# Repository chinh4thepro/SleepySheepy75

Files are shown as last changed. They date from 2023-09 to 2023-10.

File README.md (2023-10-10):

# SleepySheepy75

Making a keyboard cause im bored

## Hardware

Uses a soldered on rp2040 as the MCU
- 85x diodes for each switch (one extra for knob switch)
- 1x rotary encoder (EC11(E))
- 84x hotswap sockets
- 1x W25Q128JVS as flash rom
- 1x USB-C as connector 
- 2x buttons for "boot" selection
- Other stuff for electrical stuff

## Software

It is to be ported to QMK and be supported with VIA/VIAL

## Design

TODO - Probably going to happen when I get the pcb, case is going to be available in variety of materials

## Progress

- [x] Design the schematic (Done on 2023-09-08)
- [x] Come up with a name + Design logo (Done on 2023-10-07 (Scrapped on PCB though))
- [x] Design the PCB (Done on 2023-09-17)
- [ ] Order the PCB and its parts
- [ ] Construct PCB
- [ ] Port QMK + VIA/VIAL
- [ ] Design case for a 3d printer
- [ ] Design case for acrylic stacking
- [ ] Design case for metal CNC

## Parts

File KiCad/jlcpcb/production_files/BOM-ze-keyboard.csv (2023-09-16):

Comment | Designator | Footprint | LCSC
1k | R6,R8 | R_0402_1005Metric | C11702
100nF | C13,C14,C15,C16,C2,C5,C6,C7 | C_0402_1005Metric | C1525
10uF | C3 | C_0603_1608Metric | C15525
22pF | C10,C12 | C_0402_1005Metric | C1555
USB_C_Receptacle_USB2.0 | J2 | USB_C_Receptacle_HRO_TYPE-C-31-M-12 | C165948
RP2040 | U2 | QFN-56-1EP_7x7mm_P0.4mm_EP3.2x3.2mm | C2040
500mA | F1 | Fuse_1206_3216Metric | C20798
10k | R11,R12 | R_0402_1005Metric | C25744
27 | R1,R2 | R_0402_1005Metric | C25771
5.1k | R3,R4,R5,R7,R9 | R_0402_1005Metric | C25905
Flash | SW1,SW2 | SW_SPST_TL3342 | C318884
RotaryEncoder_Switch | SW3 | RotaryEncoder_Alps_EC11E-Switch_Vertical_H20mm | C470710
MX_SW_HS | MX1,MX10,MX11,MX12,MX13,MX14,MX15,MX16,MX17,MX18,MX19,MX2,MX20,MX21,MX22,MX23,MX24,MX25,MX26,MX27,MX28,MX29,MX3,MX30,MX31,MX32,MX33,MX34,MX35,MX36,MX37,MX38,MX39,MX4,MX40,MX41,MX42,MX43,MX44,MX45,MX46,MX47,MX48,MX49,MX5,MX50,MX51,MX52,MX53,MX54,MX55,MX56,MX57,MX58,MX59,MX6,MX60,MX61,MX62,MX63,MX64,MX65,MX66,MX67,MX68,MX69,MX7,MX70,MX71,MX72,MX73,MX74,MX75,MX76,MX77,MX78,MX79,MX8,MX80,MX81,MX82,MX83,MX84,MX9 | SW_MX_HS_1u | C5156480
1uF | C1,C11,C4,C8,C9 | C_0402_1005Metric | C52923
XC6206PxxxMR | U1 | SOT-23-3 | C5446
Crystal_GND24_Small | Y1 | Crystal_SMD_3225-4Pin_3.2x2.5mm | C5765981
ESC | D1,D10,D11,D12,D13,D14,D15,D16,D17,D18,D19,D2,D20,D21,D22,D23,D24,D25,D26,D27,D28,D29,D3,D30,D31,D32,D33,D34,D35,D36,D37,D38,D39,D4,D40,D41,D42,D43,D44,D45,D46,D47,D48,D49,D5,D50,D51,D52,D53,D54,D55,D56,D57,D58,D59,D6,D60,D61,D62,D63,D64,D65,D66,D67,D68,D69,D7,D70,D71,D72,D73,D74,D75,D76,D77,D78,D79,D8,D80,D81,D82,D83,D84,D85,D9 | D_SOD-123 | C81598
SRV05-4 | U4 | SOT-23-6-routable | C85364
W25Q128JVS | U3 | SOIC-8_5.23x5.23mm_P1.27mm | C97521

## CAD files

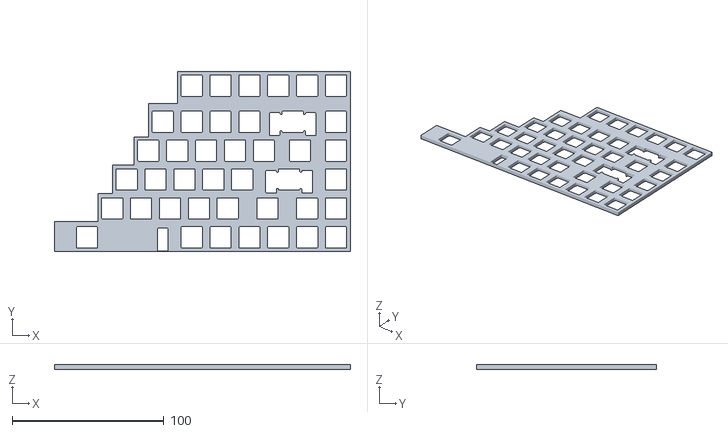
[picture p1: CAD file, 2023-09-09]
Plate/plate_half2.stl
195.3 x 119.1 x 3.00

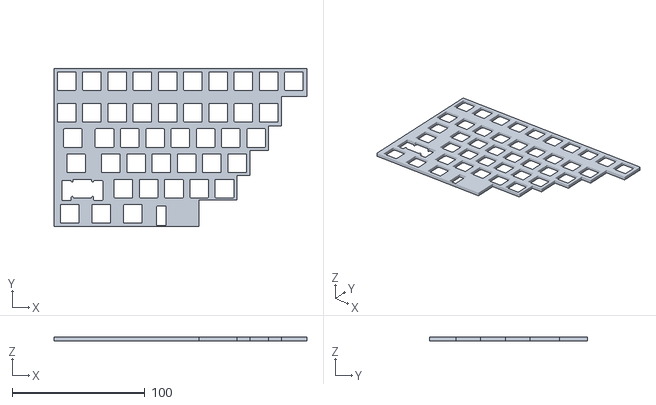
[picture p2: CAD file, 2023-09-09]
Plate/plate_half1.stl
190.8 x 119.1 x 3.00

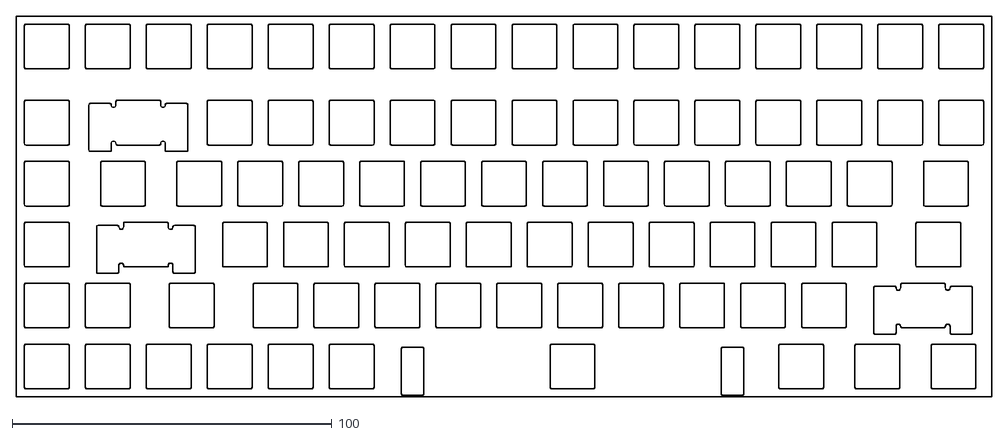
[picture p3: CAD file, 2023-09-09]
Plate/Plate-Combined.dxf
304.8 x 119.1

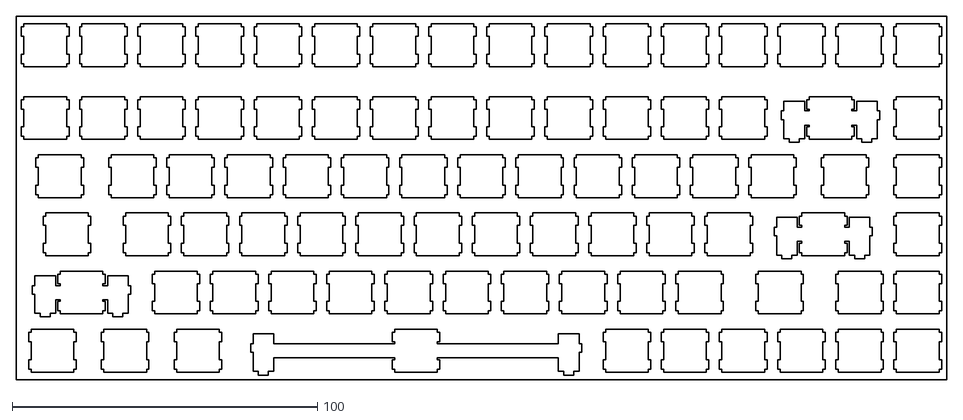
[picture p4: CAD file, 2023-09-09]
Plate/Keyboard_Plate_flat.dxf
304.8 x 119.1

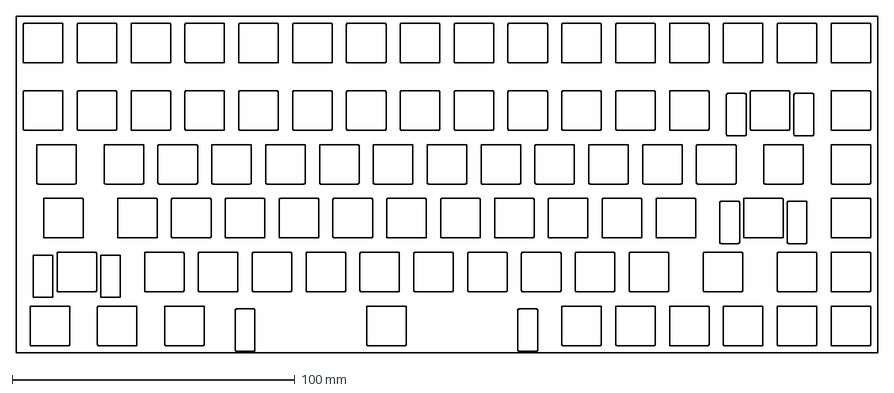
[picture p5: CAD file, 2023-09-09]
Plate/plate_ai03.dxf
304.8 x 119.1 mm

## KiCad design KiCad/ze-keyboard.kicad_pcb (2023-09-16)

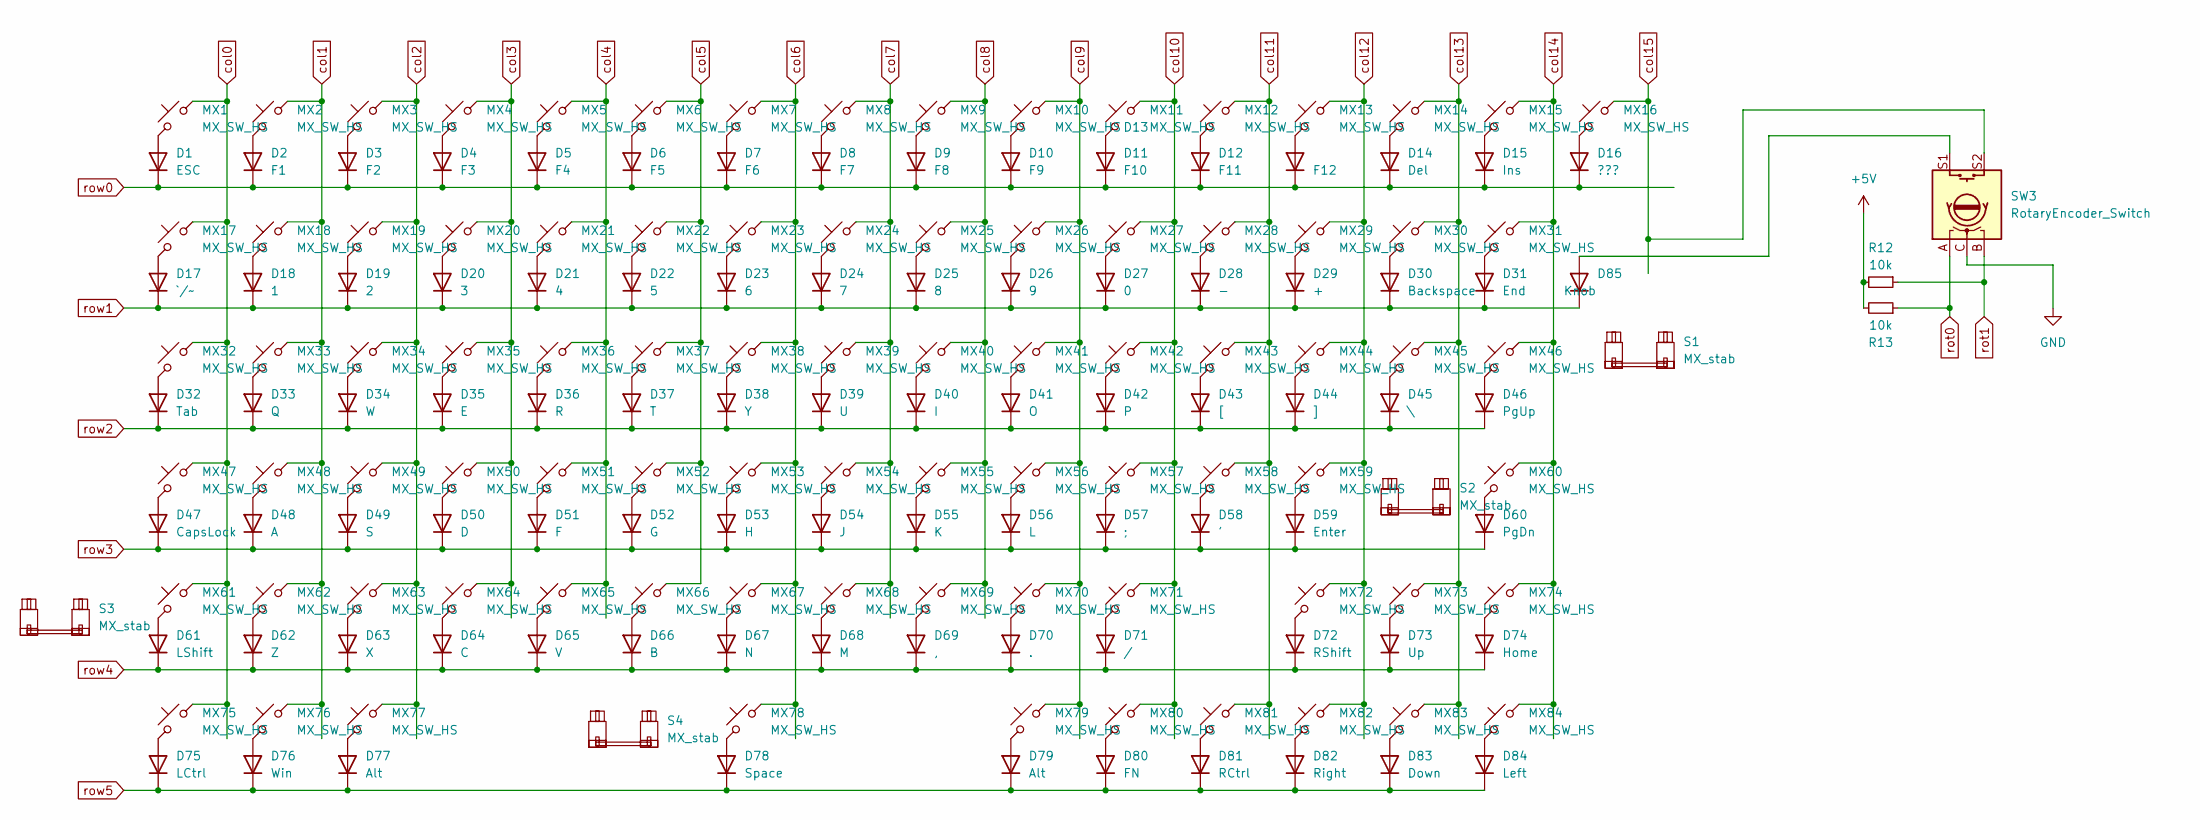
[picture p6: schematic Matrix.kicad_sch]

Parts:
D1: ESC; D_SOD-123
D2: F1; D_SOD-123
D3: F2; D_SOD-123
D4: F3; D_SOD-123
D5: F4; D_SOD-123
D6: F5; D_SOD-123
D7: F6; D_SOD-123
D8: F7; D_SOD-123
D9: F8; D_SOD-123
D10: F9; D_SOD-123
D11: F10; D_SOD-123
D12: F11; D_SOD-123
D13: F12; D_SOD-123
D14: Del; D_SOD-123
D15: Ins; D_SOD-123
D16: ???; D_SOD-123
D17: `/~; D_SOD-123
D18: 1; D_SOD-123
D19: 2; D_SOD-123
D20: 3; D_SOD-123
D21: 4; D_SOD-123
D22: 5; D_SOD-123
D23: 6; D_SOD-123
D24: 7; D_SOD-123
D25: 8; D_SOD-123
D26: 9; D_SOD-123
D27: 0; D_SOD-123
D28: -; D_SOD-123
D29: +; D_SOD-123
D30: Backspace; D_SOD-123
D31: End; D_SOD-123
D32: Tab; D_SOD-123
D33: Q; D_SOD-123
D34: W; D_SOD-123
D35: E; D_SOD-123
D36: R; D_SOD-123
D37: T; D_SOD-123
D38: Y; D_SOD-123
D39: U; D_SOD-123
D40: I; D_SOD-123
D41: O; D_SOD-123
D42: P; D_SOD-123
D43: [; D_SOD-123
D44: ]; D_SOD-123
D45: \; D_SOD-123
D46: PgUp; D_SOD-123
D47: CapsLock; D_SOD-123
D48: A; D_SOD-123
D49: S; D_SOD-123
D50: D; D_SOD-123
D51: F; D_SOD-123
D52: G; D_SOD-123
D53: H; D_SOD-123
D54: J; D_SOD-123
D55: K; D_SOD-123
D56: L; D_SOD-123
D57: ;; D_SOD-123
D58: '; D_SOD-123
D59: Enter; D_SOD-123
D60: PgDn; D_SOD-123
D61: LShift; D_SOD-123
D62: Z; D_SOD-123
D63: X; D_SOD-123
D64: C; D_SOD-123
D65: V; D_SOD-123
D66: B; D_SOD-123
D67: N; D_SOD-123
D68: M; D_SOD-123
D69: ,; D_SOD-123
D70: .; D_SOD-123
D71: /; D_SOD-123
D72: RShift; D_SOD-123
D73: Up; D_SOD-123
D74: Home; D_SOD-123
D75: LCtrl; D_SOD-123
D76: Win; D_SOD-123
D77, D79: Alt; D_SOD-123
D78: Space; D_SOD-123
D80: FN; D_SOD-123
D81: RCtrl; D_SOD-123
D82: Right; D_SOD-123
D83: Down; D_SOD-123
D84: Left; D_SOD-123
D85: Knob; D_SOD-123
MX1, MX2, MX3, MX4, MX5, MX6, MX7, MX8, MX9, MX10, MX11, MX12, MX13, MX14, MX15, MX16, MX17, MX18, MX19, MX20, MX21, MX22, MX23, MX24, MX25, MX26, MX27, MX28, MX29, MX30, MX31, MX32, MX33, MX34, MX35, MX36, MX37, MX38, MX39, MX40, MX41, MX42, MX43, MX44, MX45, MX46, MX47, MX48, MX49, MX50, MX51, MX52, MX53, MX54, MX55, MX56, MX57, MX58, MX59, MX60, MX61, MX62, MX63, MX64, MX65, MX66, MX67, MX68, MX69, MX70, MX71, MX72, MX73, MX74, MX75, MX76, MX77, MX78, MX79, MX80, MX81, MX82, MX83, MX84: MX_SW_HS; SW_MX_HS_1u
R12, R13: 10k; R_0402_1005Metric
S1, S2, S3: MX_stab; STAB_MX_P_2u
S4: MX_stab; STAB_MX_P_6.25u
SW3: RotaryEncoder_Switch; RotaryEncoder_Alps_EC11E-Switch_Vertical_H20mm

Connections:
+5V: R12.2; also elsewhere on the board
GND: SW3.C; also elsewhere on the board
unnamed: D1.2 (A), MX1.1
unnamed: D2.2 (A), MX2.1
unnamed: D3.2 (A), MX3.1
unnamed: D4.2 (A), MX4.1
unnamed: D5.2 (A), MX5.1
unnamed: D6.2 (A), MX6.1
unnamed: D7.2 (A), MX7.1
unnamed: D8.2 (A), MX8.1
unnamed: D9.2 (A), MX9.1
unnamed: D10.2 (A), MX10.1
unnamed: D11.2 (A), MX11.1
unnamed: D12.2 (A), MX12.1
unnamed: D13.2 (A), MX13.1
unnamed: D14.2 (A), MX14.1
unnamed: D15.2 (A), MX15.1
unnamed: D16.2 (A), MX16.1
unnamed: D17.2 (A), MX17.1
unnamed: D18.2 (A), MX18.1
unnamed: D19.2 (A), MX19.1
unnamed: D20.2 (A), MX20.1
unnamed: D21.2 (A), MX21.1
unnamed: D22.2 (A), MX22.1
unnamed: D23.2 (A), MX23.1
unnamed: D24.2 (A), MX24.1
unnamed: D25.2 (A), MX25.1
unnamed: D26.2 (A), MX26.1
unnamed: D27.2 (A), MX27.1
unnamed: D28.2 (A), MX28.1
unnamed: D29.2 (A), MX29.1
unnamed: D30.2 (A), MX30.1
unnamed: D31.2 (A), MX31.1
unnamed: D32.2 (A), MX32.1
unnamed: D33.2 (A), MX33.1
unnamed: D34.2 (A), MX34.1
unnamed: D35.2 (A), MX35.1
unnamed: D36.2 (A), MX36.1
unnamed: D37.2 (A), MX37.1
unnamed: D38.2 (A), MX38.1
unnamed: D39.2 (A), MX39.1
unnamed: D40.2 (A), MX40.1
unnamed: D41.2 (A), MX41.1
unnamed: D42.2 (A), MX42.1
unnamed: D43.2 (A), MX43.1
unnamed: D44.2 (A), MX44.1
unnamed: D45.2 (A), MX45.1
unnamed: D46.2 (A), MX46.1
unnamed: D47.2 (A), MX47.1
unnamed: D48.2 (A), MX48.1
unnamed: D49.2 (A), MX49.1
unnamed: D50.2 (A), MX50.1
unnamed: D51.2 (A), MX51.1
unnamed: D52.2 (A), MX52.1
unnamed: D53.2 (A), MX53.1
unnamed: D54.2 (A), MX54.1
unnamed: D55.2 (A), MX55.1
unnamed: D56.2 (A), MX56.1
unnamed: D57.2 (A), MX57.1
unnamed: D58.2 (A), MX58.1
unnamed: D59.2 (A), MX59.1
unnamed: D60.2 (A), MX60.1
unnamed: D61.2 (A), MX61.1
unnamed: D62.2 (A), MX62.1
unnamed: D63.2 (A), MX63.1
unnamed: D64.2 (A), MX64.1
unnamed: D65.2 (A), MX65.1
unnamed: D66.2 (A), MX66.1
unnamed: D67.2 (A), MX67.1
unnamed: D68.2 (A), MX68.1
unnamed: D69.2 (A), MX69.1
unnamed: D70.2 (A), MX70.1
unnamed: D71.2 (A), MX71.1
unnamed: D72.2 (A), MX72.1
unnamed: D73.2 (A), MX73.1
unnamed: D74.2 (A), MX74.1
unnamed: D75.2 (A), MX75.1
unnamed: D76.2 (A), MX76.1
unnamed: D77.2 (A), MX77.1
unnamed: D78.2 (A), MX78.1
unnamed: D79.2 (A), MX79.1
unnamed: D80.2 (A), MX80.1
unnamed: D81.2 (A), MX81.1
unnamed: D82.2 (A), MX82.1
unnamed: D83.2 (A), MX83.1
unnamed: D84.2 (A), MX84.1
unnamed: D85.2 (A), SW3.S1
col0: MX1.2, MX17.2, MX32.2, MX47.2, MX61.2, MX75.2; also elsewhere on the board
col1: MX2.2, MX18.2, MX33.2, MX48.2, MX62.2, MX76.2; also elsewhere on the board
col2: MX3.2, MX19.2, MX34.2, MX49.2, MX63.2, MX77.2; also elsewhere on the board
col3: MX4.2, MX20.2, MX35.2, MX50.2, MX64.2; also elsewhere on the board
col4: MX5.2, MX21.2, MX36.2, MX51.2, MX65.2; also elsewhere on the board
col5: MX6.2, MX22.2, MX37.2, MX52.2, MX66.2; also elsewhere on the board
col6: MX7.2, MX23.2, MX38.2, MX53.2, MX67.2, MX78.2; also elsewhere on the board
col7: MX8.2, MX24.2, MX39.2, MX54.2, MX68.2; also elsewhere on the board
col8: MX9.2, MX25.2, MX40.2, MX55.2, MX69.2; also elsewhere on the board
col9: MX10.2, MX26.2, MX41.2, MX56.2, MX70.2, MX79.2; also elsewhere on the board
col10: MX11.2, MX27.2, MX42.2, MX57.2, MX71.2, MX80.2; also elsewhere on the board
col11: MX12.2, MX28.2, MX43.2, MX58.2, MX81.2; also elsewhere on the board
col12: MX13.2, MX29.2, MX44.2, MX59.2, MX72.2, MX82.2; also elsewhere on the board
col13: MX14.2, MX30.2, MX45.2, MX73.2, MX83.2; also elsewhere on the board
col14: MX15.2, MX31.2, MX46.2, MX60.2, MX74.2, MX84.2; also elsewhere on the board
col15: MX16.2, SW3.S2; also elsewhere on the board
row0: D1.1 (K), D2.1 (K), D3.1 (K), D4.1 (K), D5.1 (K), D6.1 (K), D7.1 (K), D8.1 (K), D9.1 (K), D10.1 (K), D11.1 (K), D12.1 (K), D13.1 (K), D14.1 (K), D15.1 (K), D16.1 (K); also elsewhere on the board
row1: D17.1 (K), D18.1 (K), D19.1 (K), D20.1 (K), D21.1 (K), D22.1 (K), D23.1 (K), D24.1 (K), D25.1 (K), D26.1 (K), D27.1 (K), D28.1 (K), D29.1 (K), D30.1 (K), D31.1 (K), D85.1 (K); also elsewhere on the board
row2: D32.1 (K), D33.1 (K), D34.1 (K), D35.1 (K), D36.1 (K), D37.1 (K), D38.1 (K), D39.1 (K), D40.1 (K), D41.1 (K), D42.1 (K), D43.1 (K), D44.1 (K), D45.1 (K), D46.1 (K); also elsewhere on the board
row3: D47.1 (K), D48.1 (K), D49.1 (K), D50.1 (K), D51.1 (K), D52.1 (K), D53.1 (K), D54.1 (K), D55.1 (K), D56.1 (K), D57.1 (K), D58.1 (K), D59.1 (K), D60.1 (K); also elsewhere on the board
row4: D61.1 (K), D62.1 (K), D63.1 (K), D64.1 (K), D65.1 (K), D66.1 (K), D67.1 (K), D68.1 (K), D69.1 (K), D70.1 (K), D71.1 (K), D72.1 (K), D73.1 (K), D74.1 (K); also elsewhere on the board
row5: D75.1 (K), D76.1 (K), D77.1 (K), D78.1 (K), D79.1 (K), D80.1 (K), D81.1 (K), D82.1 (K), D83.1 (K), D84.1 (K); also elsewhere on the board

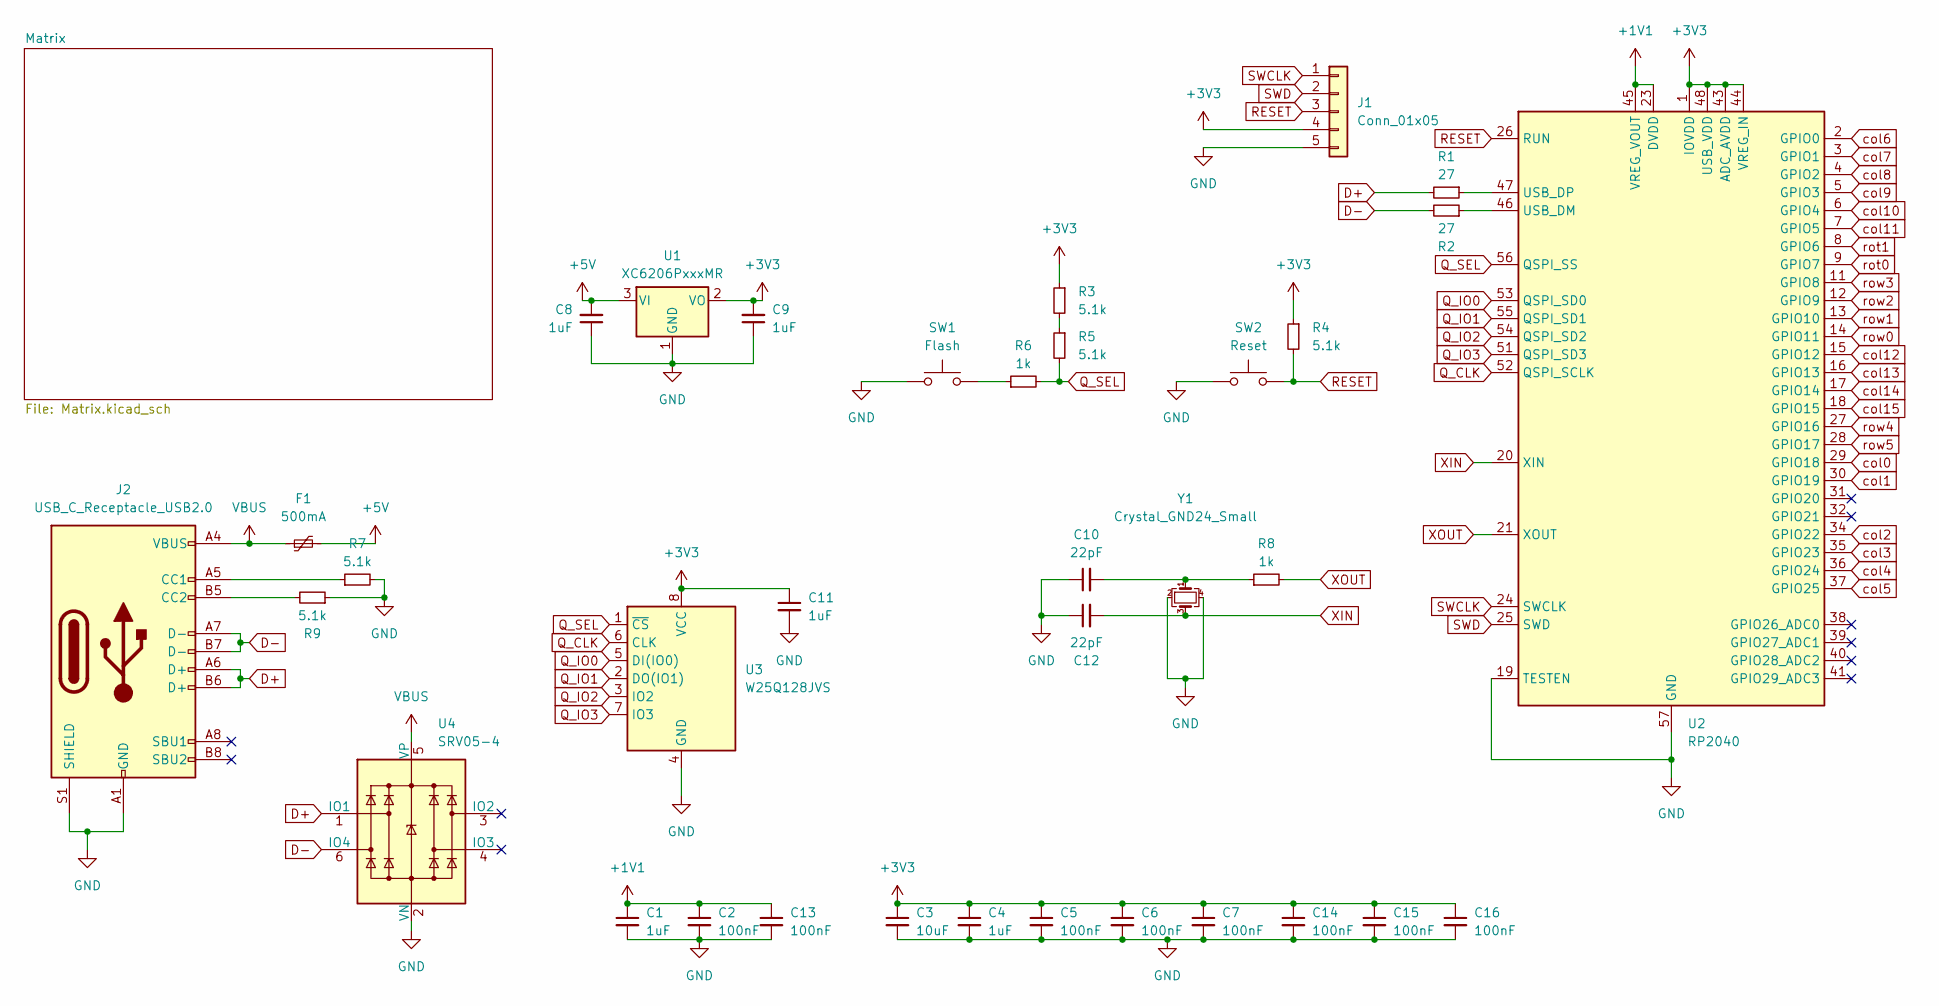
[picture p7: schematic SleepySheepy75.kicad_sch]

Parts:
C1, C4, C8, C9, C11: 1uF; C_0402_1005Metric
C2, C5, C6, C7, C13, C14, C15, C16: 100nF; C_0402_1005Metric
C3: 10uF; C_0603_1608Metric
C10, C12: 22pF; C_0402_1005Metric
F1: 500mA; Fuse_1206_3216Metric
J1: Conn_01x05; PinHeader_1x05_P2.54mm_Vertical
J2: USB_C_Receptacle_USB2.0; USB_C_Receptacle_HRO_TYPE-C-31-M-12
R1, R2: 27; R_0402_1005Metric
R3, R4, R5, R7, R9: 5.1k; R_0402_1005Metric
R6, R8: 1k; R_0402_1005Metric
SW1: Flash; SW_SPST_TL3342
SW2: Reset; SW_SPST_TL3342
U1: XC6206PxxxMR; SOT-23-3
U2: RP2040; QFN-56-1EP_7x7mm_P0.4mm_EP3.2x3.2mm
U3: W25Q128JVS; SOIC-8_5.23x5.23mm_P1.27mm
U4: SRV05-4; SOT-23-6-routable
Y1: Crystal_GND24_Small; Crystal_SMD_3225-4Pin_3.2x2.5mm

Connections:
+1V1: C1.1, C2.1, C13.1, U2.23 (DVDD), U2.45 (VREG_VOUT), U2.50 (DVDD)
+3V3: C3.1, C4.1, C5.1, C6.1, C7.1, C9.2, C11.1, C14.1, C15.1, C16.1, J1.4, R3.1, R4.1, U1.2 (VO), U2.1 (IOVDD), U2.10 (IOVDD), U2.22 (IOVDD), U2.33 (IOVDD), U2.42 (IOVDD), U2.43 (ADC_AVDD), U2.44 (VREG_IN), U2.48 (USB_VDD), U2.49 (IOVDD), U3.8 (VCC)
+5V: C8.2, F1.2, U1.3 (VI); also elsewhere on the board
D+: J2.A6 (D+), J2.B6 (D+), R1.2, U4.1 (IO1)
D-: J2.A7 (D-), J2.B7 (D-), R2.2, U4.6 (IO4)
GND: C1.2, C2.2, C3.2, C4.2, C5.2, C6.2, C7.2, C8.1, C9.1, C10.1, C11.2, C12.1, C13.2, C14.2, C15.2, C16.2, J1.5, J2.A1 (GND), J2.A12 (GND), J2.B1 (GND), J2.B12 (GND), J2.S1 (SHIELD), R7.2, R9.1, SW1.1, SW2.1, U1.1 (GND), U2.19 (TESTEN), U2.57 (GND), U3.4 (GND), U4.2 (VN), Y1.2, Y1.4; also elsewhere on the board
unnamed: C10.2, R8.1, Y1.1
unnamed: J2.A5 (CC1), R7.1
unnamed: J2.B5 (CC2), R9.2
unnamed: R3.2, R5.1
unnamed: R6.1, SW1.2
unnamed: R2.1, U2.46 (USB_DM)
unnamed: R1.1, U2.47 (USB_DP)
Q_CLK: U2.52 (QSPI_SCLK), U3.6 (CLK)
Q_IO0: U2.53 (QSPI_SD0), U3.5 (DI(IO0))
Q_IO1: U2.55 (QSPI_SD1), U3.2 (DO(IO1))
Q_IO2: U2.54 (QSPI_SD2), U3.3 (IO2)
Q_IO3: U2.51 (QSPI_SD3), U3.7 (IO3)
Q_SEL: R5.2, R6.2, U2.56 (QSPI_SS), U3.1 (~CS)
RESET: J1.3, R4.2, SW2.2, U2.26 (RUN)
SWCLK: J1.1, U2.24 (SWCLK)
SWD: J1.2, U2.25 (SWD)
VBUS: F1.1, J2.A4 (VBUS), J2.A9 (VBUS), J2.B4 (VBUS), J2.B9 (VBUS), U4.5 (VP)
XIN: C12.2, U2.20 (XIN), Y1.3
XOUT: R8.2, U2.21 (XOUT)
col0: U2.29 (GPIO18); also elsewhere on the board
col1: U2.30 (GPIO19); also elsewhere on the board
col2: U2.34 (GPIO22); also elsewhere on the board
col3: U2.35 (GPIO23); also elsewhere on the board
col4: U2.36 (GPIO24); also elsewhere on the board
col5: U2.37 (GPIO25); also elsewhere on the board
col6: U2.2 (GPIO0); also elsewhere on the board
col7: U2.3 (GPIO1); also elsewhere on the board
col8: U2.4 (GPIO2); also elsewhere on the board
col9: U2.5 (GPIO3); also elsewhere on the board
col10: U2.6 (GPIO4); also elsewhere on the board
col11: U2.7 (GPIO5); also elsewhere on the board
col12: U2.15 (GPIO12); also elsewhere on the board
col13: U2.16 (GPIO13); also elsewhere on the board
col14: U2.17 (GPIO14); also elsewhere on the board
col15: U2.18 (GPIO15); also elsewhere on the board
row0: U2.14 (GPIO11); also elsewhere on the board
row1: U2.13 (GPIO10); also elsewhere on the board
row2: U2.12 (GPIO9); also elsewhere on the board
row3: U2.11 (GPIO8); also elsewhere on the board
row4: U2.27 (GPIO16); also elsewhere on the board
row5: U2.28 (GPIO17); also elsewhere on the board

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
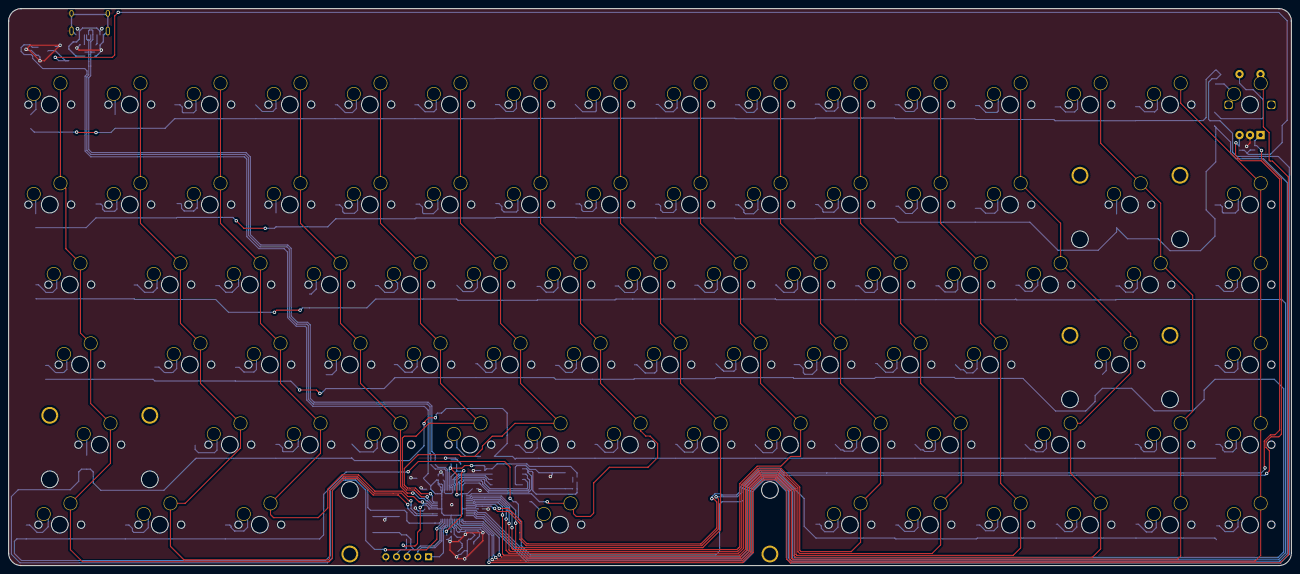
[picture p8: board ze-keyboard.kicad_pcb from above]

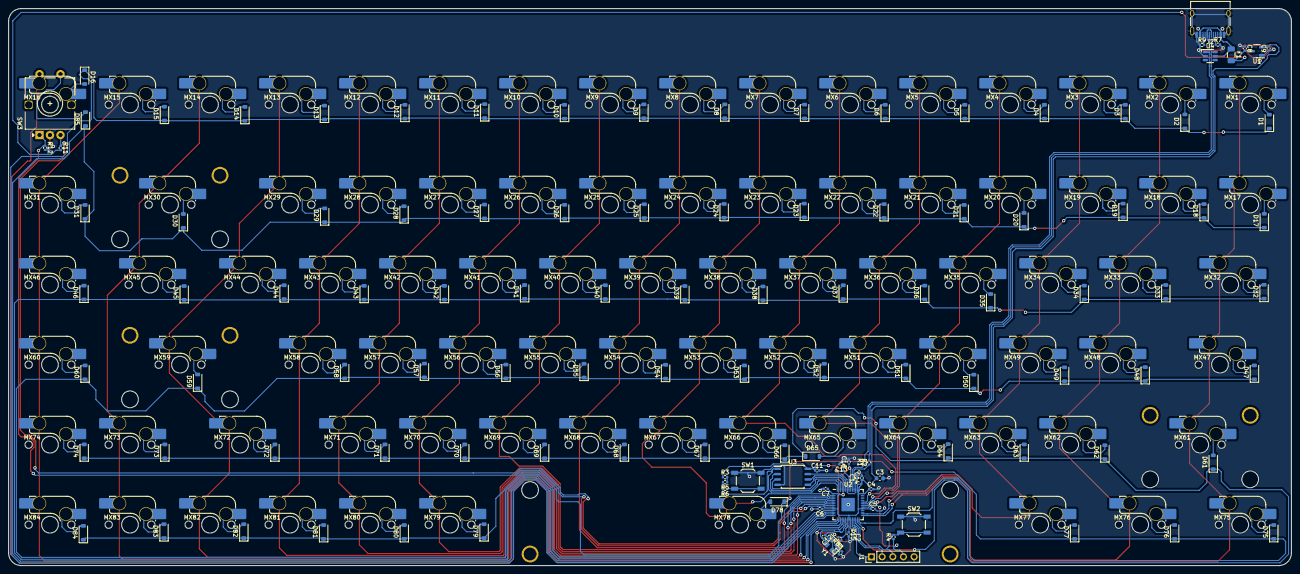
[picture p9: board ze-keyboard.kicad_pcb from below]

Board: 2 copper layers, 305.4 x 132.6 mm, 211 parts (211 on the bottom side), 134 nets.

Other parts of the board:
R11: 10k; R_0402_1005Metric

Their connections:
+5V: R11.2; also elsewhere on the board

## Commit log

2023-09-08 Add kicad files
    [ze-keyboard.kicad_pcb, ze-keyboard.kicad_sch]
2023-09-08 move files out of directory
    [ze-keyboard.kicad_pcb, ze-keyboard.kicad_sch]
2023-09-08 remove the directory
    [ze-keyboard.kicad_pcb, ze-keyboard.kicad_sch]
2023-09-09 move kicad stuff into the directory again and add Plate
    [Keyboard_Plate_flat.dxf, Matrix.kicad_sch, plate_ai03.dxf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]
2023-09-09 remove clutter from the root
    [ze-keyboard.kicad_pcb, ze-keyboard.kicad_sch]
2023-09-09 "finish" the keyboard schematics
    [Matrix.kicad_sch, Plate-Combined.dxf, ze-keyboard.kicad_sch]
2023-09-09 add plate 3d model
    [Plate-Combined.dxf]
2023-09-09 add split plate
    [plate_half1.stl, plate_half2.stl]
2023-09-11 fix stuff... i forgot the other stuff i added
    [Matrix.kicad_sch, ze-keyboard.kicad_pcb, ze-keyboard.kicad_sch]
2023-09-12 fix flipped keyboard, and finish routing mcu
    [ze-keyboard.kicad_pcb]
2023-09-12 add traces to diodes to their respective switches, and fix holes on knob
2023-09-12 do some tracing
    [Matrix.kicad_sch, ze-keyboard.kicad_sch]
2023-09-13 finish pcb
    [Matrix.kicad_sch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]
2023-09-14 do some more stuff like fixing most of 90 degree traces
    [ze-keyboard.kicad_pcb]
2023-09-14 some changes, a bit more jlcpcb stuff
    [BOM-ze-keyboard.csv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]
2023-09-14 MORE JCBPCB STUFF
    [ze-keyboard.kicad_pcb]
2023-09-15 jlcpcb stuff
    [BOM-ze-keyboard.csv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]
2023-09-16 PCB AND JLCPCB STUFF DONE!!!
    [BOM-ze-keyboard.csv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]
2023-09-17 more jlcpcb stuff
    [CPL-ze-keyboard.csv, ze-keyboard-CuBottom.gbr, ze-keyboard-CuTop.gbr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]
2023-09-28 rename files
    [SleepySheepy75-CuBottom.gbr, SleepySheepy75-CuTop.gbr, SleepySheepy75-EdgeCuts.gbr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]
